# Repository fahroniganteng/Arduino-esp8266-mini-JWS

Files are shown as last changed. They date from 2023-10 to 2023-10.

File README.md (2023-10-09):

# Arduino-esp8266-mini-JWS

Mini JWS (Jam Waktu Sholat) dengan ESP8266 dan Matrix LED MAX7219

## Fitur

- Koneksi jam dengan wifi
- Seting jam dengan web base
- Update waktu ke NTP Server  
  Desain jam ini update waktu ke NTP server di internet (`time.google.com, pool.ntp.org, time.windows.com`), namun jika dalam jaringan (LAN) anda memiliki NTP server, maka jam bisa bekerja tanpa koneksi internet.  
  Untuk alamat NTP server bisa diganti pada seting jam.
  > Anda perlu menambahkan modul RTC dan memodifikasi kode jika ingin jam benar-benar offline.
- Beberapa tema jam
- Durasi pergantian dapat disesuaikan
- Menampilkan jam waktu sholat  
  - Perhitungan jam sholat menggunakan lokasi (koordinat) dan timezone
  - Metode perhitungan kemenag :
    - Subuh : 20 deg
    - Asar : Perbandingan bayangan 1 (Shafi'i dan lainnya)
    - Isya : 18 deg
  > CATATAN :  
  > Untuk library JWS yang digunakan adalah [Arduino-Prayer-Times](https://github.com/asmaklad/Arduino-Prayer-Times) yang merupakan adaptasi dari [http://praytimes.org/](http://praytimes.org/).  
  > Library ini sebenarnya mendukung beberapa metode perhitungan :
  >
  > - MWL : Muslim World League
  > - ISNA : Islamic Society of North America
  > - Egypt : Egyptian General Authority of Survey
  > - Makkah : Umm al-Qura University, Makkah
  > - Karachi : University of Islamic Sciences, Karachi
  > - Tehran : Institute of Geophysics, University of Tehran
  > - Jafari : Shia Ithna Ashari (Ja`fari)
  > - Custom : Custom setting
  >
  > Namun pada menu seting jam yang ditampilkan hanya metode kemenag (metode custom), jika anda memerlukan menggunakan metode perhitungan lain, anda harus mengganti di code nya

## Video Demo & Instalasi

DEMO (https://youtu.be/aN8uahImBbo)

## Komponen

- ESP8266 board (Wemos, nodemcu, etc)
- Matrix led (MAX7219)
- 5V power supply (bisa menggunakan charger HP)

## Wiring

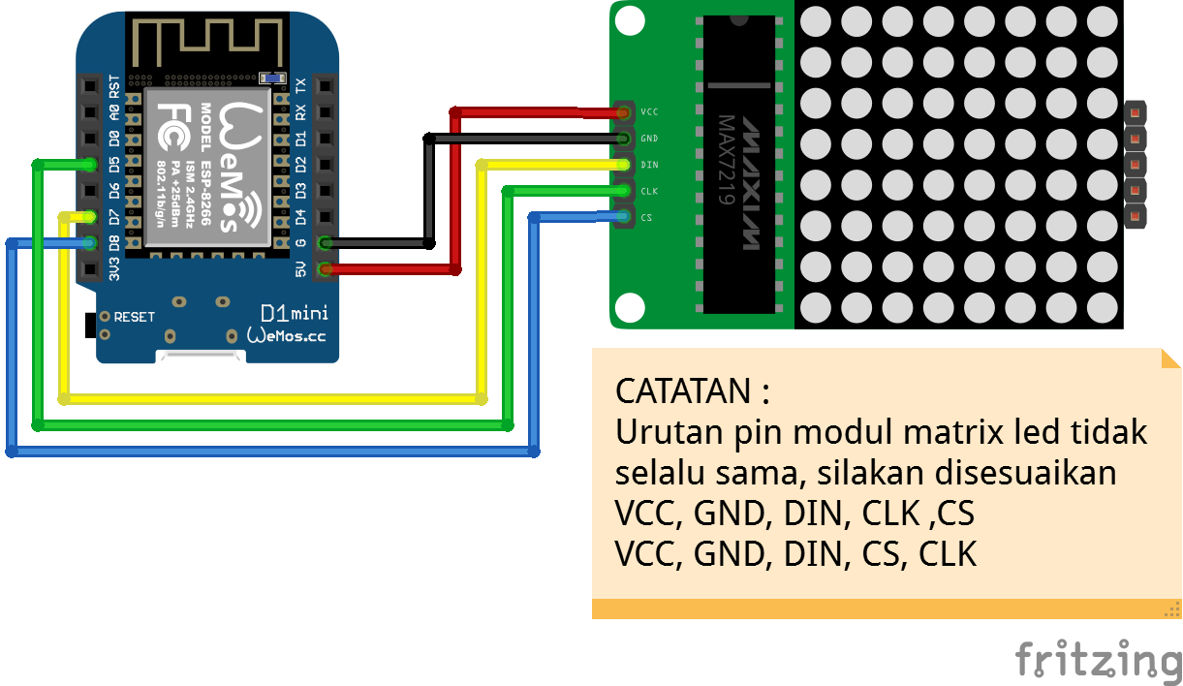
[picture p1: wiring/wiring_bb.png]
Wiring

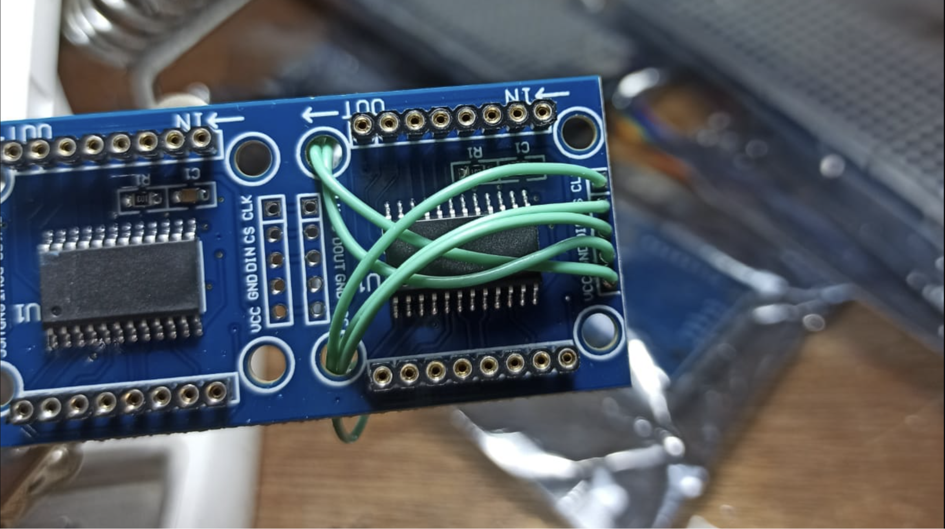
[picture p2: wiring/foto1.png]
Foto1

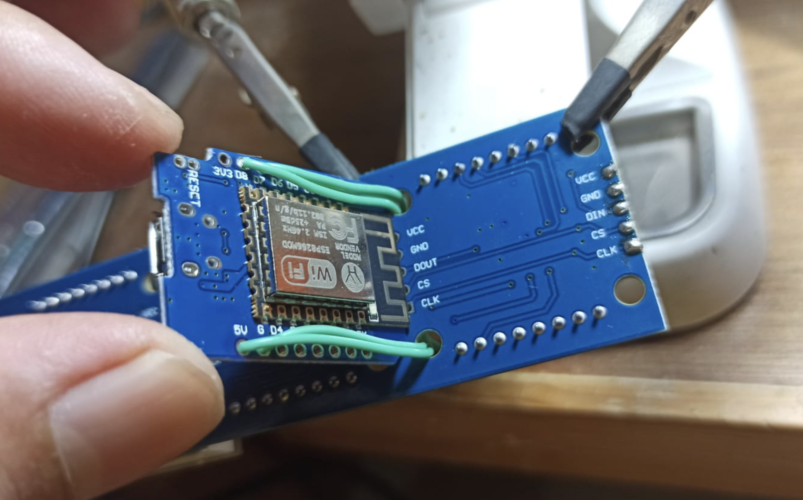
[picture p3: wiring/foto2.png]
Foto2


## Software , Driver dan Instalasi 

Baberapa board ESP8266 seperti wemos dan nodeMCU menggunakan chip CH340 untuk serial komunikas, anda bisa download drivernya dari link berikut:

- Install driver CH340 [check here](https://learn.sparkfun.com/tutorials/how-to-install-ch340-drivers/all)

> CATATAN :  
> Dalam beberapa kasus, untuk OS windows 10 dan windows 11, driver CH340 versi terbaru otomatis terinstal dari windows update, namun tidak bisa digunakan untuk upload sketch ke ESP8266.  
> Solusinya anda perlu install manual driver versi lama (link diatas)

Ada 2 cara untuk upload ke board ESP8622, silakan sesuaikan dengan kebutuhan anda.
(untuk lebih lengkapnya anda bisa lihat tutorial pada video diatas)

### 1. Dengan ESP Tool

Jika anda hanya ingin install saja tanpa modifikasi kode, menggunkan ESP Tool adalah cara yang cepat dan lebih mudah.  

- Cek port Wemos yang terkoneksi pada PC dari device manager
- Buka file `upload.bat` pada folder `bin` dengan text editor kemudian sesuaikan port-nya
- Jalankan `upload.bat`

  ```bat
    esptool.py v4.6.2
    Serial port COM10
    Connecting....
    Chip is ESP8266EX
    Features: WiFi
    Crystal is 26MHz
    MAC: 24:d7:eb:ca:6b:a4
    Uploading stub...
    Running stub...
    Stub running...
    Changing baud rate to 921600
    Changed.
    Configuring flash size...
    Flash will be erased from 0x00000000 to 0x00060fff...
    Compressed 394144 bytes to 280538...
    Wrote 394144 bytes (280538 compressed) at 0x00000000 in 4.0 seconds (effective 792.8 kbit/s)...
    Hash of data verified.

    Leaving...
    Hard resetting via RTS pin...
    Press any key to continue . . .
  ```

  > CATATAN :
  > - Tutorial diata adalah untuk OS Windows.
  > - Untuk OS lain silakan mendownload ESP Tool sesuai versi OS-nya [cek disini](https://github.com/espressif/esptool/releases)
  > - File bin (`wemos.bin`) adalah binary yang di compile untuk board wemos, tidak bisa digunakan untuk board ESP8266 yang lain.
  
### 2. Dengan Arduino IDE

Jika anda memerlukan untuk melakukan modifikasi kode, anda bisa menggunakan Arduino IDE.

- Install arduino IDE [cek disini](https://www.arduino.cc/)
- Tambahkan board ESP8266 pada arduino IDE [cek disini](https://github.com/esp8266/Arduino)
- Buka `code.ino` pada folder `code`
- Lakukan modifikasi kode jika diperlukan
- Sesuaikan jenis board dan port-nya, kemudian upload sketch.

## Box

Berikut adalah box yang pernah saya bikin dengan 3D Printer, namun untuk ukuran PCB modul matrix led tidak selalu sama, mungkin akan memerlukan beberapa penyesuaian dengan modul yang anda beli.
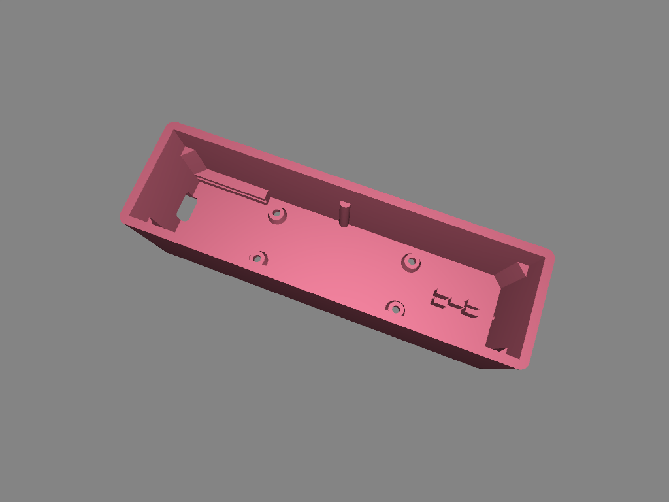
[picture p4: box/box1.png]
box1

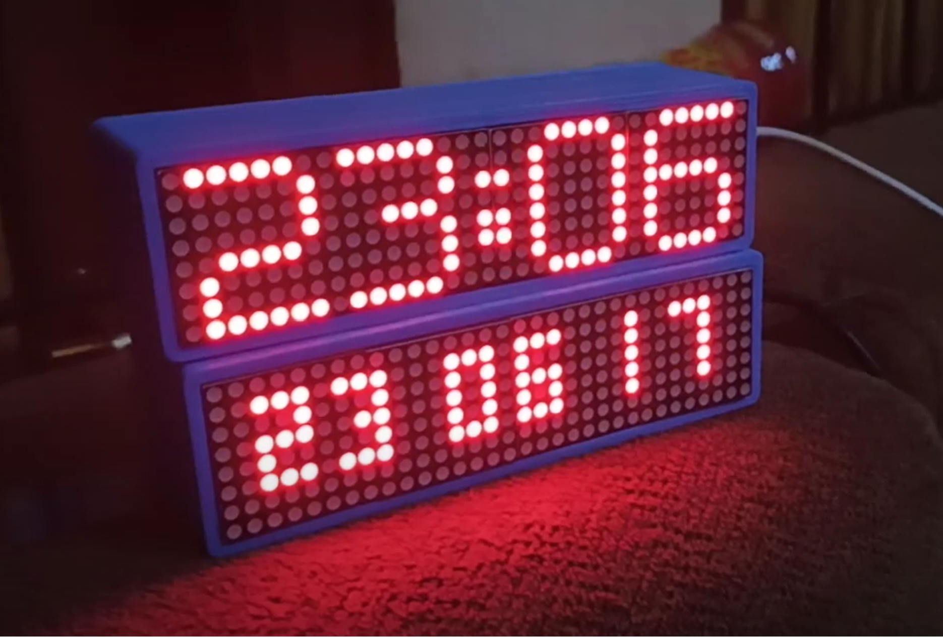
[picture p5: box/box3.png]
box3


## Seting Jam

Secara default, saat pertama kali selesai diinstal perangkat akan menjadi access point wifi :

- SSID = JAM-JWS
- Tanpa password

Setelah melakukan koneksi dengan access point diatas, untuk masuk ke halaman seting jam silakan buka browser dengan alamat <http://10.10.10.10/> kemudian ikuti petunjuk yang ada dalam menu seting jam untuk mengkoneksikan jam dengan wifi dan melakukan setting JWS. (silakan buka video tutorial untuk lebih detailnya)

Perangkat akan otomatis menjadi access point kembali jika gagal melakukan koneksi dengan wifi (yang di set di seting jam).

## License and credits

My code under MIT license, other libraries follow their own license.

## Donation  

Support me  

- [Send me coffee](https://sociabuzz.com/fahroniganteng/tribe)
- [or maybe ice cream](https://trakteer.id/fahroniganteng/tip)

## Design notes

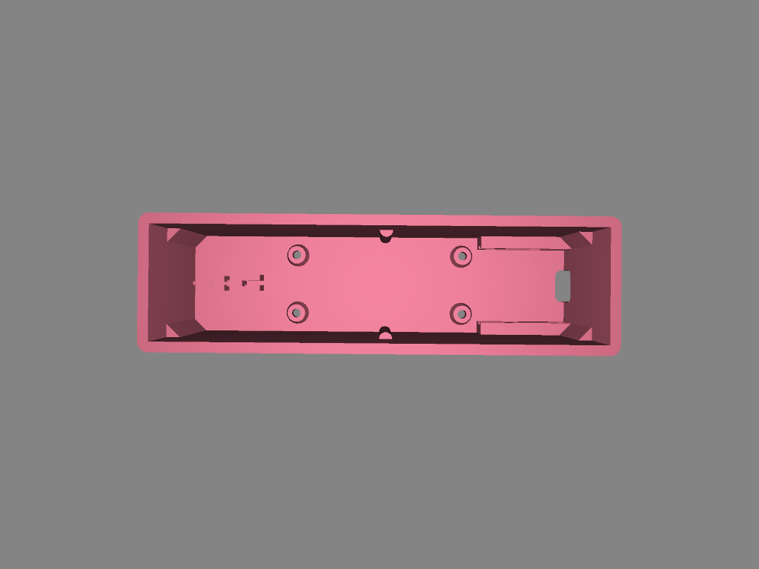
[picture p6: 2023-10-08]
box/box2.png

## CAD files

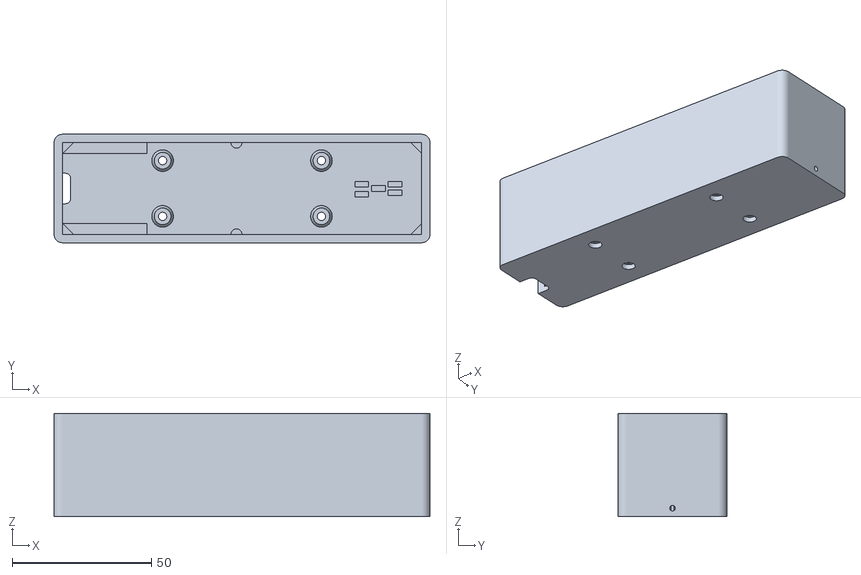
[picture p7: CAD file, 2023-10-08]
box/box.stl
135.0 x 39.0 x 37.0

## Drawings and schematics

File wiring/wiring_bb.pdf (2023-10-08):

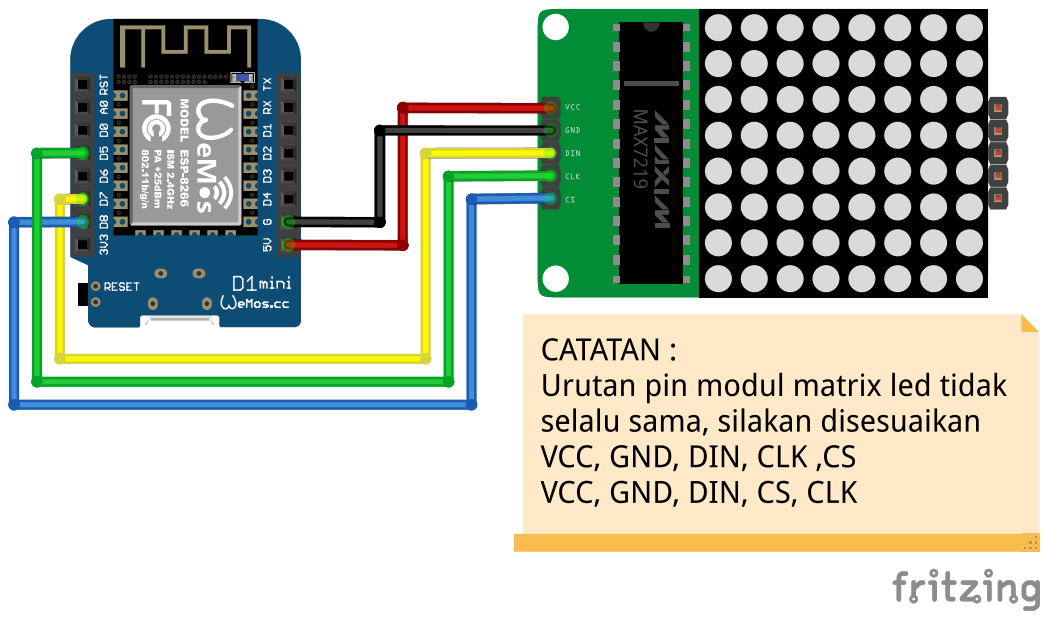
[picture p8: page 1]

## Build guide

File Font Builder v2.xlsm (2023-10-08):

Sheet: Instructions
MD_MAX72xx and Parola Font Editor v2.1
Purpose
The purpose of this workbook is to simplify the coding of LED matrix font files for the MD_MAX72xx and MD_Parola libraries. All characters are 8 or 16 pixels high and can be as wide as necessary. This tool allows up to 10 columns.
Principles of Operation
The font definitions are a series of bytes representing columns of data (one column of the LED display) preceded by the number of bytes in that definition. This allows both variable size characters and fixed size characters to be defined in the same way. The ASCII code for the character is inferred from the position in the file (i.e., the 100th character definition is for ASCII value 99, as numbering starts at 0).
5, 62, 107, 79, 107, 62, // 2 - Happy Smiley
In the above example, 5 is the number of bytes in the definition and the remaining bytes are the bitmap for the character. The comment line is auto generated by this tool to include the ASCII value and the optional label entered for this character.
Workflow
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

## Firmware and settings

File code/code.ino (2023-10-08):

/**
 * @file code.ino
 * @author fahroni|ganteng (fahroniganteng@gmail.com)
 * @brief 
 * @version 1.0
 * @date 2023-10-08
 * 
 * @copyright Copyright (c) 2023
 * 
 */

#include <math.h> // buat ngitung suhu (fungsi log)
#include "NTPClient.h"
#include <ESP8266WiFi.h>
#include <WiFiUdp.h>
#include <ESP8266WebServer.h>
#include <EEPROM.h>
#include "Timer.h"
// #include "time.h"
#include "ronnLedAnimation.h" //==> FUNGSI ANIMASI MATRIX LED PINDAH SINI SEMUA BIAR GAK PUSING BACA NYA....

// FUNCTION HITUNG HARI
#define SECS_PER_MIN (60UL)
#define SECS_PER_HOUR (3600UL)
#define SECS_PER_DAY (SECS_PER_HOUR * 24L)

#define getSEC(_time_) (_time_ % SECS_PER_MIN)
#define getMIN(_time_) ((_time_ / SECS_PER_MIN) % SECS_PER_MIN)
#define getHOUR(_time_) ((_time_ % SECS_PER_DAY) / SECS_PER_HOUR)
#define getDAY(_time_) (_time_ / SECS_PER_DAY)

// Variable Timer
Timer tmr;
int tmrEvJam; // Event buat menampilkan jam di matrix led

int ledIntensity = 0; // kecerahan led
float timeZone;				// buat simpan zona waktu --> ada yang GMT -3:30 --> -3.5 jadinya pake float

// EEPROM Function
#include "ronnEeprom.h"
// JWS Function
#include "ronnJws.h"
// Wifi Function
#include "ronnWifi.h"
// NTP Function
#include "ronnNtp.h"

void setIntensity()
{
	String buf = readEEPROM("intensity");
	ledIntensity = (buf.length() == 5 || buf.length() == 0) ? 0 : buf.toInt(); // if eeprom not valid
	ledIntensity = ledIntensity > 10 ? 10 : ledIntensity;											 // kecerahan max 10 (biar awet)
	mx.control(MD_MAX72XX::INTENSITY, ledIntensity);													 // 0-15  --> #define MAX_INTENSITY 0xf
}

int shJws = 10; // on startup diganti dari eeprom
int shTgl = 30; // on startup diganti dari eeprom
int shKustomText = 0;
String kustomText = "";
String jsonData = "";
#include "ronnHtml.h" // move here --> biar enak dibaca

/**
 * MATRIX LED FUNCTION
 * *************************************************************************
 * TSL  --> Transform Shift Left one pixel element
 * TSR  --> Transform Shift Right one pixel element
 * TSU  --> Transform Shift Up one pixel element
 * TSD  --> Transform Shift Down one pixel element
 * TFLR --> Transform Flip Left to Right
 * TFUD --> Transform Flip Up to Down
 * TRC  --> Transform Rotate Clockwise 90 degrees
 * TINV --> Transform INVert (pixels inverted)
 */
int loopDetik = 0;
int loopDetik1 = 0;
String old_time = "xx:xx"; // hhii
bool jamOnDisplay = false;

// big font 00:00
void shJamStyle1()
{
	String new_time = ntp_jam.substring(0, 5);
	if (!jamOnDisplay)
	{
		clearLeft();
		mx.setFont(font_ICON);
		scrollDown(12, 10, "9");
		delay(300);
		clearRight();
		mx.setFont(font_JAM1); // ganti font
		printTextRight(new_time, 2);
		loopDetik = 6; // biar langsung bergerak;
	}

	uint8_t detik[20] = {':', ':', ':', ':', ':', ':', ':', ';', '<', '=', '>', '>', '>', '>', '>', '>', '>', '=', '<', ';'}; // di font dipake detik semua
	mx.setFont(font_JAM1);																																																		// ganti font
	mx.setChar(16, detik[loopDetik]);

	// String new_time = ntp_jam.substring(3,8); //Ambil detik buat tes
	if (old_time != new_time)
	{
		mx.setFont(font_JAM1); // ganti font
		mx.setChar(31 - 1, new_time[0]);
		mx.setChar(23, new_time[1]);
		mx.setChar(15 - 2, new_time[3]);
		mx.setChar(7 - 1, new_time[4]);
		old_time = new_time;
	}

	jamOnDisplay = true;
	loopDetik = loopDetik < 19 ? loopDetik + 1 : 0;
}

// icon + 00:00
void shJamStyle2()
{
	String detik = "EEFFGGHHIIJJKKLL"; // kasih 1 kecepeten
	String detik1 = "::::;;;;;";
	String new_time = ntp_jam.substring(0, 5);
	mx.setFont(font_ICON);
	if (!jamOnDisplay)
	{
		clearLeft();
		loopDetik = 0;
		loopDetik1 = 1;
		animIcon(String(detik[loopDetik]));
		delay(200);
		mx.setFont(font_4X7); // ganti font
		printText(new_time, 11);
	}
	else
	{
		printText(String(detik[loopDetik]), 1);		 // icon
		mx.setFont(font_4X7);											 // ganti font
		printText(String(detik1[loopDetik1]), 21); // titik dua (:)
		if (new_time != old_time)
		{
			printText(new_time, 11);
			old_time = new_time;
		}
	}
	// Serial.println(loopDetik);

	jamOnDisplay = true;
	loopDetik = loopDetik < detik.length() - 1 ? loopDetik + 1 : 0;
	loopDetik1 = loopDetik1 < detik1.length() - 1 ? loopDetik1 + 1 : 0;
}

// small font 00:00:00
int animStyle3 = 0;
void shJamStyle3()
{
	String detik = "::::;;;;;";
	mx.setFont(font_3X5); // ganti font

	if (!jamOnDisplay)
	{ // pertama load (animasi)
		clearRight();
		animIcon("G");
		delay(200);
		mx.setFont(font_3X5);												// ganti font
		scrollDown(23, 7, ntp_jam.substring(3, 5)); // menit
		delay(100);
		scrollDown(13, 7, ntp_jam.substring(0, 2)); // jam
		printText(":", 21);
		animStyle3 = 20;
	}
	else if (animStyle3 > 0)
	{
		printText(String(detik[loopDetik]), 21);
		// menit
		if (ntp_jam.substring(3, 4) != old_time.substring(3, 4))
			scrollDown(13, 7, ntp_jam.substring(3, 5));
		else if (ntp_jam.substring(4, 5) != old_time.substring(4, 5))
			scrollDown(17, 3, ntp_jam.substring(4, 5));
		// jam
		if (ntp_jam.substring(0, 1) != old_time.substring(0, 1))
			scrollDown(3, 7, ntp_jam.substring(0, 2));
		else if (ntp_jam.substring(1, 2) != old_time.substring(1, 2))
			scrollDown(7, 3, ntp_jam.substring(1, 2));

		animStyle3--;
		if (animStyle3 < 1)
		{
			for (uint8_t i = 0; i <= 9; i++)
			{
				mx.transform(MD_MAX72XX::TSL);
				delay(10);
			}
			delay(100);
			printText(ntp_jam.substring(6, 8), 23);
			// scrollDown(23,7,ntp_jam.substring(6,8));//detik
			printText(String(detik[loopDetik]), 21);
			// printText("/0",11);
		}
	}
	else
	{
		// ntp_jam = 00:00:00 --> 0,2 jam; 3,5 menit; 6,8 detik

		// show titik dua (:)
		printText(String(detik[loopDetik]), 11);
		printText(String(detik[loopDetik]), 21);
		// detik
		if (ntp_jam.substring(6, 7) != old_time.substring(6, 7))
			scrollDown(23, 7, ntp_jam.substring(6, 8));
		else if (ntp_jam.substring(7, 8) != old_time.substring(7, 8))
			scrollDown(27, 3, ntp_jam.substring(7, 8));
		// menit
		if (ntp_jam.substring(3, 4) != old_time.substring(3, 4))
			scrollDown(13, 7, ntp_jam.substring(3, 5));
		else if (ntp_jam.substring(4, 5) != old_time.substring(4, 5))
			scrollDown(17, 3, ntp_jam.substring(4, 5));
		// jam
		if (ntp_jam.substring(0, 1) != old_time.substring(0, 1))
			scrollDown(3, 7, ntp_jam.substring(0, 2));
		else if (ntp_jam.substring(1, 2) != old_time.substring(1, 2))
			scrollDown(7, 3, ntp_jam.substring(1, 2));

		// printText(ntp_jam,3);
	}

	old_time = ntp_jam;
	jamOnDisplay = true;
	loopDetik = loopDetik < detik.length() - 1 ? loopDetik + 1 : 0;
}

// Pergantian style jam
int jamStyle = 3;
void shJam()
{
	if (ntp_jam == "--no data--")
		return;
	else if (jamStyle == 3)
		shJamStyle3();
	else if (jamStyle == 2)
		shJamStyle2();
	else
		shJamStyle1();
}
void changeJamStyle()
{
	if (jamStyle == 3)
		jamStyle = 2;
	else if (jamStyle == 2)
		jamStyle = 1;
	else
		jamStyle = 3;
}

int shTglAfter = 0;
int shJwsAfter = 0;
int countSts = 0;
int countApMode = 0;
bool errorNtp = false;
bool errorWifi = false;
void runApplication()
{
	// cek clienr connect pada mode soft-AP
	softap_stations_cnt = wifi_softap_get_station_num();
	// Serial.println(softap_stations_cnt);

	if (ntp_all != "--no data--")
		errorNtp = false;
	if (WiFi.status() == WL_CONNECTED)
		errorWifi = false;

	int detik = ntp_jam.substring(6, 8).toInt();
	if (apMode)
	{
		String icon = "EFGHIJKL";
		mx.setFont(font_ICON);									 // ganti font
		printText(String(icon[countApMode]), 1); // icon
		countApMode = countApMode < icon.length() - 1 ? countApMode + 1 : 0;
	}

	else if (WiFi.status() != WL_CONNECTED)
	{
		if (errorWifi)
			return; // biar nggak berulang animasi nya
		tmr.stop(tmrEvJam);
		tmr.stop(tmrEvJam);
		clearLeft();
		animIcon("8");
		mx.setFont(font_3X5); // ganti font
		scrollDown(16, 32, "OFF");
		jamOnDisplay = false;
		countSts = 1;
		errorWifi = true;
	}

	else if (ntp_all == "--no data--")
	{
		if (errorNtp)
			return; // biar nggak berulang animasi nya
		tmr.stop(tmrEvJam);
		clearLeft();
		animIcon("7");
		mx.setFont(font_5X8);
		scrollDown(12, 32, "NTP");
		jamOnDisplay = false;
		countSts = 1;
		errorNtp = true;
	}

	// CUSTOM TEXT____________________________________________________________
	else if (kustomText.length() > 0 && detik % shKustomText == 0)
	{
		tmr.stop(tmrEvJam);
		clearRight();
		mx.setFont(font_ICON);
		scrollDown(13, 8, ":"); // icon text
		delay(400);
		for (uint8_t i = 0; i <= MAX_DEVICES * 8; i++)
		{
			mx.transform(MD_MAX72XX::TSL);
			delay(7);
		}
		mx.setFont(font_default); // default font
		scrollText(kustomText + "           ");
		countSts = 1;
		jamOnDisplay = false;
		changeJamStyle();
	}

	// DAY ___________________________________________________________________________
	else if (detik % shTgl == 0)
	{
		tmr.stop(tmrEvJam);
		clearRight();
		animIcon("1");
		mx.setFont(font_5X8);
		scrollDown(12, 32, ntp_tgl.substring(0, 3));
		shTglAfter = 10;
	}

	// DATE ___________________________________________________________________________
	else if (shTglAfter == 8)
	{
		scrollDown(8, 32, "\0");
		for (uint8_t i = 0; i <= MAX_DEVICES * 8; i++)
		{
			mx.transform(MD_MAX72XX::TSR);
			delay(5);
		}
		mx.setFont(font_5X8);
		printTextRight(ntp_tgl.substring(5, 11), 2);
	}

	// YEAR __________________________________________________________________________
	else if (shTglAfter == 6)
	{
		clearRight();
		animIcon("0");
		delay(25);
		mx.setFont(font_SUHU);
		scrollDown(10, 32, ntp_tgl.substring(12, 16));
		countSts = 2; // 2 detik baru ganti jam
		jamOnDisplay = false;
		changeJamStyle();
	}

	// JWS ___________________________________________________________________________
	else if (detik % shJws == 0)
	{
		tmr.stop(tmrEvJam);
		clearUp();
		mx.setFont(font_ICON);
		scrollDown(12, 10, "2");
		delay(400);
		clearRight();
		mx.setFont(font_4X7); // ganti font
		printTextRight(prayName[prayShow], 2);
		shJwsAfter = 10;
	}
	else if (shJwsAfter == 8)
	{
		clearLeft();
		delay(200);
		animIcon("2");
		delay(200);
		mx.setFont(font_4X7); // ganti font
		scrollDown(10, 32, String(prayTime[prayShow]));
		countSts = 3; // 3 detik baru ganti jam
		jamOnDisplay = false;
		changeJamStyle();
	}

	// CLOCK _________________________________________________________________________
	else if (countSts == 0)
	{
		if (tmr.status(tmrEvJam) == 0)
			tmrEvJam = tmr.every(100, shJam);
	}

	if (countSts >= 0)
		countSts--; // no process status= -1
	if (shTglAfter > 0)
		shTglAfter--; // no process date = 0
	if (shJwsAfter > 0)
		shJwsAfter--; // no process date = 0
}

void setup()
{
	Serial.begin(115200);
	delay(100);
	Serial.println();
	EEPROM.begin(512);

	/**
	 * How to reset EEPROM for simulation first upload sketch to board:
	 * - Enable (un-comment) the code "resetEEPROM()" below and upload sketch to ESP board
	 * - Disable code, and then upload sketch again
	 **/
	// resetEEPROM();

	pinMode(LED_BUILTIN, OUTPUT); // LED BUILTIN = D4
	pinMode(A0, INPUT);						// thermistor ==> temp
	delay(10);
	digitalWrite(LED_BUILTIN, LOW);

	// File system start (file on flash memory --> html,js,css and friends) ----------------------------
	SPIFFS.begin();
	String buf; // buffer

	// Matrix Led -----------------------------------------------------------------------
	mx.begin();
	setIntensity();
	mx.clear();

	// RONI GANTENG SHOW ^___^
	delay(300);
	mx.setFont(font_ICON); // ganti font
	scrollDown(1, 8, "A");
	delay(100);
	scrollDown(9, 8, "B");
	delay(100);
	scrollDown(17, 8, "C");
	delay(100);
	scrollDown(25, 8, "D");
	delay(1000);
	clearLeft();

	// show animasi & tulisan clock
	scrollDown(13, 8, "E");
	delay(400);
	for (uint8_t i = 0; i <= 11; i++)
	{
		mx.transform(MD_MAX72XX::TSL);
		delay(5);
	}
	delay(200);
	mx.setFont(font_3X5); // ganti font
	scrollDown(11, 32, "CLOCK");
	mx.setFont(font_ICON);
	buf = "FGHIJKLEFGH";
	for (uint8_t i = 0; i <= buf.length(); i++)
	{
		printText(String(buf[i]), 1);
		delay(100);
	}

	// Wifi_______________________________________________________
	WiFi.persistent(false);
	Serial.println("Connecting wifi...");
	connectWifi();
	// show jam pasir
	if (!apMode)
	{ // AP mode muncul tulisan AP MODE di diplay
		clearUp();
		mx.setFont(font_ICON);
		scrollDown(13, 8, "V");
	}
	// handle html request
	serverOnHandleClient();

	// start http server
	server.begin();
	Serial.println("HTTP server started");

	// matiin led();
	digitalWrite(LED_BUILTIN, HIGH); // matiin led bawaan (HIGH = mati) --> i dont know why... :D

	// Waktu tampil jam & suhu
	shJws = readEEPROM("shJws").toInt();
	shJws = shJws < 5 ? 30 : shJws; // proteksi pertama load, EEPROM kosong (xx mod 0 = ERROR)
	shTgl = readEEPROM("shTgl").toInt();
	shTgl = shTgl < 5 ? 60 : shTgl; // proteksi pertama load, EEPROM kosong (xx mod 0 = ERROR)

	// Get EEPROM location
	Serial.println("Get Location ");
	buf = readEEPROM("latitude");
	buf = (buf.length() == 15 || buf.length() == 0) ? "-6.0889" : buf; // if eeprom not valid
	location_lat = buf.toFloat();
	buf = readEEPROM("longitude");
	buf = (buf.length() == 15 || buf.length() == 0) ? "106.9967" : buf; // if eeprom not valid
	location_long = buf.toFloat();
	Serial.print(location_lat, 4);
	Serial.print(", ");
	Serial.println(location_long, 4);

	// Get EEPROM Timezone
	Serial.print("Get NTP Offset : GMT ");
	buf = readEEPROM("gmt");
	buf = (buf.length() == 10 || buf.length() == 0) ? "7" : buf; // if eeprom not valid
	timeZone = buf.toFloat();
	timeZone = (timeZone < -12 || timeZone > 12) ? 7 : timeZone; // if timeZone not valid
	Serial.println(timeZone);

	// Butuh dapet key array event dulu buat dapet tmr.status--> soalnya tak modif lib. timer nya... :D
	tmrEvJam = tmr.oscillate(LED_BUILTIN, 50, HIGH, 1);
	delay(100);
	tmr.every(60 * 1000, reConnectWifi); // jika gagal konek wifi, otomatis re-connect tiap 1 menit
	tmr.every(1000, uptime);						 // update uptime

	// NTP
	configNtp();
	delay(1000);
	tmr.every(100, getNtpDate);
	tmr.every(60 * 1000, []() { // force update tiap 1 menit
		timeClient.forceUpdate();
	});

	tmr.every(1000, runApplication);
}

void loop()
{
	tmr.update();
	server.handleClient();
	timeClient.update();
}

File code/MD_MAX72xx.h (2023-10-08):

#pragma once

#include <Arduino.h>

/**
 * \file
 * \brief Main header file for the MD_MAX72xx library
 */

/**
\mainpage Arduino LED Matrix Library
The Maxim 72xx LED Controller IC
--------------------------------
The MAX7219/MAX7221 are compact, serial input/output display drivers that
interface microprocessors to 7-segment numeric LED displays of up to 8 digits,
bar-graph displays, or 64 individual LEDs. Included on-chip are a BCD code-B
decoder, multiplex scan circuitry, segment and digit drivers, and an 8x8 static
RAM that stores each digit.

A 4-wire serial interface (SPI) allows the devices to be cascaded, with
communications passed through the first device in the chain to all others. Individual
elements may be addressed and updated without rewriting the entire display.

This library implements functions that allow the MAX72xx to be used
for LED matrices (64 individual LEDs), allowing the programmer to use the LED
matrix as a pixel device, displaying graphics elements much like any other
pixel addressable display.

Topics
------
- \subpage pageHardware
- \subpage pageSoftware
- \subpage pageConnect
- \subpage pageFontUtility
- \subpage pageRevisionHistory
- \subpage pageCopyright
- \subpage pageDonation

\page pageDonation Support the Library
If you like and use this library please consider making a small donation using [PayPal](https://paypal.me/MajicDesigns/4USD)

\page pageCopyright Copyright
Copyright (C) 2012-18 Marco Colli. All rights reserved.

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
\page pageRevisionHistory Revision History
Oct 2019 version 3.2.1
- First large (150 module system) - increase size of SPI counters to int16_t

Sep 2019 version 3.2.0
- Change character codes to 16 bit to allow up to 65535 characters in font table.
- Retested examples for clean compile with new version of compiler.

May 2019 version 3.1.0
- Changed font definition to more modern look.
- Font ASCII code > 127 now conforms to unicode Latin-1 supplement.

Oct 2018 version 3.0.2
- Updated to remove 'left over' serial print debug.

Aug 2018 version 3.0.1
- Fixed problem with calculating font width in info structure.

June 2018 version 3.0.0
- Implemented new font file format (file format version 1).
- Removed 'drawXXX' graphics functions to new MD_MAXPanel library.
- Removed font indexing as this never used.
- Added getFontHeight() method.
- Module type now specified at run time.

Apr 2018 version 2.11.1
- Another attempt to further clarify editing of header file for hardware changes.

Apr 2018 version 2.11.0
- Restructured header file to make hardware flags more obvious
- Added drawHLine(), drawVLine(), drawRectangle() methods

Mar 2018 version 2.10.1
- Reworked HW Mapping utility.
- setColumn() parameter changed from uint8_t to uint16_t to allow for more than 256 column in the matrix [BUG]

Nov 2017 version 2.10.0
- Changed SPI buffer handling and isolation of AVR specific features (eg PROGMEM)
- Added MD_MAX72xx_Message_ESP8266 example
- Minor source file cleanup
- Added Extended ASCII font, vertical rotated font and RobotEyes font in fontbuilder
- Modified font builder output code for consistency with new code
- Added getFont(), getMaxFontWidth() methods
- Changed example - replaced MD_KeySwitch with new MD_UISwitch library

Nov 2016 version 2.9.0
- Added WordClock example
- Deprecated USE_LIBRARY_SPI as no problems reported with new implementation
- Changed MD_ branding to new MajicDesigns diamond
- Small adjustments to initialization code

Mar 2016 version 2.8
- Added example Message_SD and renamed Message to Message_Serial
- Added Pacman example
- Added PushWheel example
- Added USE_LIBRARY_SPI to enable library SPI object
- Modified all examples to conditionally include <SPI.h>
- FontBuilder modified to handle definitions for double height fonts
- New txt2font utility for easier font creation from a text file
- Revised and re-organized documentation; expanded section on fonts

April 2015 version 2.7
- Changed to Daft Punk example to run without switch
- Now supporting IDE Library Manager

February 2015 version 2.6
- Improvements to HW_Mapper utility
- Added HW_USE_FC16 for FC-16 display modules
- Added USE_HW_OTHER for user defined hardware configuration
- Fixed incorrect spelling for HW_REV_COLS in transformBuffer() & corresponding bug
- Added PrintText_ML example

February 2015 version 2.5
- Documented process for adding new hardware module type
- Fixed PROGMEM definitions for IDE version 1.5.7 compile error
- Added Daft Punk example code
- Updated HW_Mapper example/utility with built-in instructions
- Minor problems with Parola font setting interaction fixed

April 2014 version 2.4
- Improved reliability of initialization code to remove artifacts
 + Changed order of hardware initialization for SS, _csPin
 + Changed initialization sequence at begin()
 + Fixed memset bug identified by bperrybap
- Reworked command SPI transmissions for efficiency
- Cleanup up compiler warnings on inline wrapper code functions
- Cleaned up examples begin() - better defined library default values
- Reviewed and tidied up some documentation

March 2014 - version 2.3
- Extensive rework of the font system
 + New Microsoft Excel VBA based font builder tool available
 + Removed USE_FONT_ADJUST and related code - replace by builder tool
 + Fixed width font has been removed from the library. Definition still available in font builder
 + fontype_t definition changed to suit new requirements
- Transform zoning implemented (contiguous subset of services)
 + Transformation functions, control, clear, setRow methods overloaded with range specifier
 + User callback for L/R rotation function syntax added a device parameter
 + New Zones example
- USE_*_HW hardware types now separated out for future flexibility
 + Rework of the library to use new schema for defining hardware characteristics
 + New utility code to map out digits and segments for unknown hardware types
- Rechecked and reworked examples for new library

November 2013 - version 2.2
- Replaced reference to SPI library with inline code to allow for different select lines
- Obsoleted INCLUDE_HARDWARE_SPI conditional compile switch
- Fixed legacy code function name error when USE_FONT_ADJUST switch turned on
- Implemented USE_PAROLA_HW to allow cheaply available matrix modules to be used in ganged mode
- Fixed reversal of bit field for set/get Row/Column functions -> flipped charset data
- Added Eyes example program
- Upgraded and reorganized documentation

June 2013 - version 2.1
- Include the selection of hardware SPI interface (10x speed improvement)
- Tidied up comments
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

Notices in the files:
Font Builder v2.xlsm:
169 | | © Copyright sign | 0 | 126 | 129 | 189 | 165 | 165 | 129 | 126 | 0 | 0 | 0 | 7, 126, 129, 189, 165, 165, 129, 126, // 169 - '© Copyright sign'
